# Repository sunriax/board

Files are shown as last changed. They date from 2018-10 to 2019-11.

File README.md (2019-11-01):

# BOARD Repository!

  

## Description

The BOARD repository is a set of Schematic and PCB files which can be used to build adapters for the STK500/STK600, Basys3 and other platforms. The design was made with Eagle and can be adapted easily. The Gerber files can also be found in the repository. We recommend to let [Elecrow](https://www.elecrow.com/) produce the PCB.

## Layouts

* [LCD Display Adapter](./display/display.md)
* [LCD Display Controller](./controller/controller.md)

## Important Notice

This files are valid for all repositories at the SUNriaX Github!
* [Readme](https://github.com/sunriax/manual/blob/master/README.md)
* [License](https://github.com/sunriax/manual/blob/master/LICENSE.md)
* [Warranty](https://github.com/sunriax/manual/blob/master/WARRANTY.md)

## Additional Information

You can find more additional information in the [manual](https://github.com/sunriax/manual/tree/master/docs) repository and/or visit the [WIKI](https://wiki.sunriax.at/) for further information (currently under construction).

If there are any further questions feel free to start an issue or contact us, we try to react as quick as possible.

---
**R. GÄCHTER, Rankweil Oct/2019**

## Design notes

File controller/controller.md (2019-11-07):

# BOARD Repository!

## Introduction

The controller layout is designed to adapt an LCD Display (e.g. Displaytech 162A/B) and control Text and other stuff through USB (UART). It can be powered through the mini USB jack. If the controller is used the first time, it it necessary to throw the [Bootloader](./Firmware/firmware.md) on the chip.

## Firmware

In [Firmware](./Firmware/firmware.md) repository the additional software to control the display is stored.

## Connection

### DISPLAY

| PIN | Function | Description |
|:---:|:---|:---|
| 1 | A | Backlight anode |
| 2 | K | Backlight cathode |
| 3 | VSS | Ground (0V) |
| 4 | VDD | Supply voltage (5V) |
| 5 | VO | Contrast Voltage |
| 6 | RS | HIGH=Data Signal/LOW=Instruction Signal  | 
| 7 | R/W | Connected to ground (0V) |
| 8 | E | Chip enable signal |
| 9 | DB0 | Data bit 0 (not connected) |
| 10  | DB1 | Data bit 1 (not connected) |
| 11  | DB2 | Data bit 2 (not connected) |
| 12  | DB3 | Data bit 3 (not connected) |
| 13  | DB4 | Data bit 4 |
| 14  | DB5 | Data bit 5 |
| 15  | DB6 | Data bit 6 |
| 16  | DB7 | Data bit 7 |

### ISP

| PIN | Function | Description |
|:---:|:---|:---|
| 1 | MISO | Master In/Slave Out |
| 2 | VCC | Power supply for ISP programming |
| 3 | SCK | Clock input |
| 4 | MOSI | Master Out/Slave In |
| 5 | RESET | System reset |
| 6 | GND | Ground connection |

## Schematic

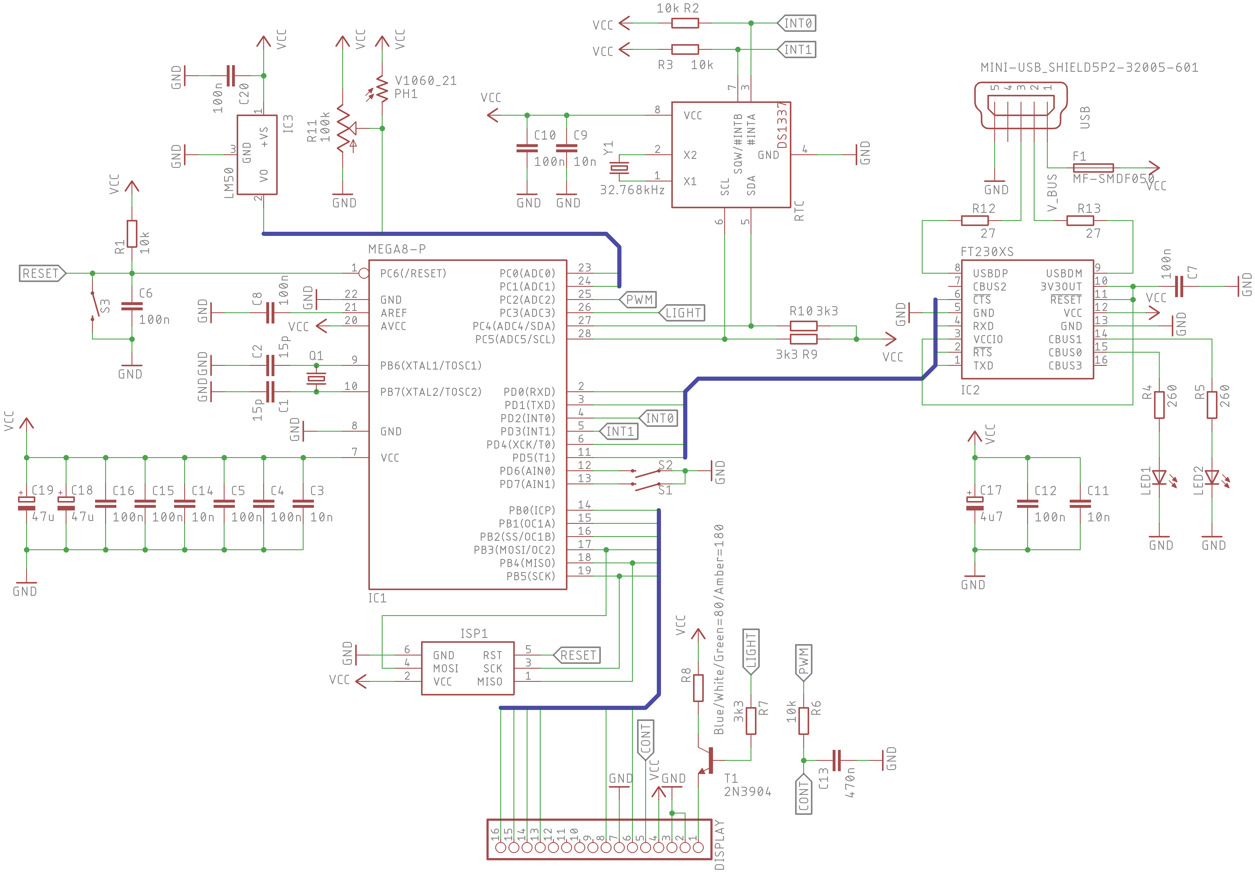
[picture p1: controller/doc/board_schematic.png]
Schematic Description


[Schematic PDF](https://raw.githubusercontent.com/sunriax/board/master/controller/doc/board_schematic.pdf)

## Board

### Bill of material

Necessary parts to build the board are documented in the THT and SMD bill of material list. We recommend to buy the parts at [RS-Components](https://at.rs-online.com/). The related numbers are deposited at the bill of material lists.

* [Bill of material THT](./partlist.csv)
* [Bill of material SMD](./partlist_SMD.csv)

### All Layers

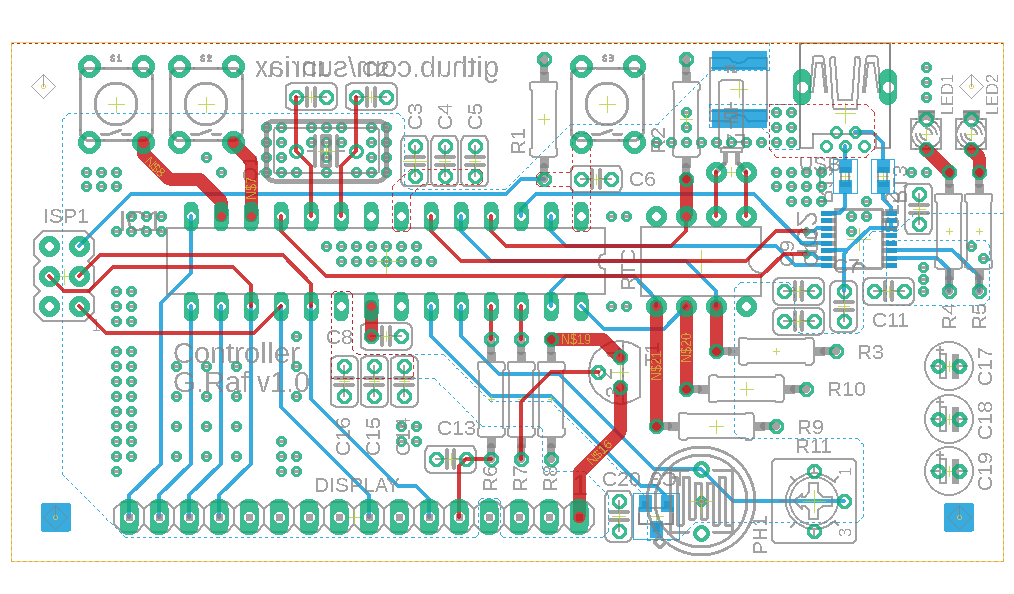
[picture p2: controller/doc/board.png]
BOARD Layer Description


[BOARD PDF](https://raw.githubusercontent.com/sunriax/board/master/controller/doc/board.pdf)

### TOP Layer

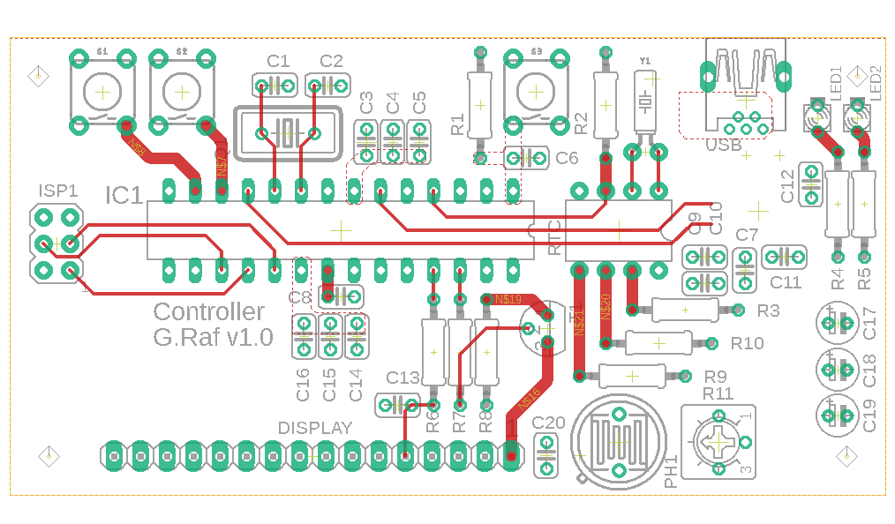
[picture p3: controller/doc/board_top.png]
TOP Layer Description


[TOP Layer PDF](https://raw.githubusercontent.com/sunriax/board/master/controller/doc/board_top.pdf)

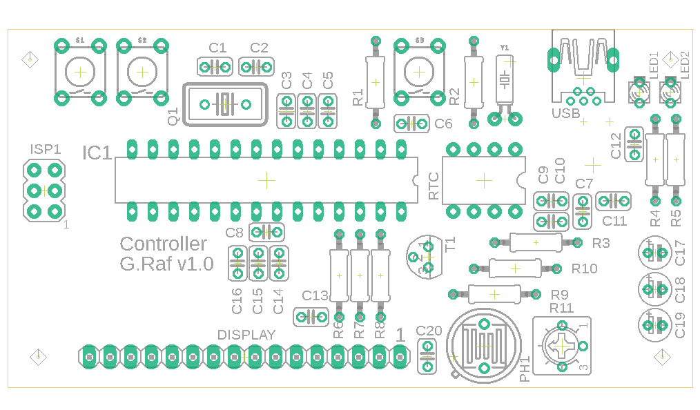
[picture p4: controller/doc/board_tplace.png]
TOP Layer Place


[TOP Layer PDF](https://raw.githubusercontent.com/sunriax/board/master/controller/doc/board_tplace.pdf)

### BOTTOM Layer

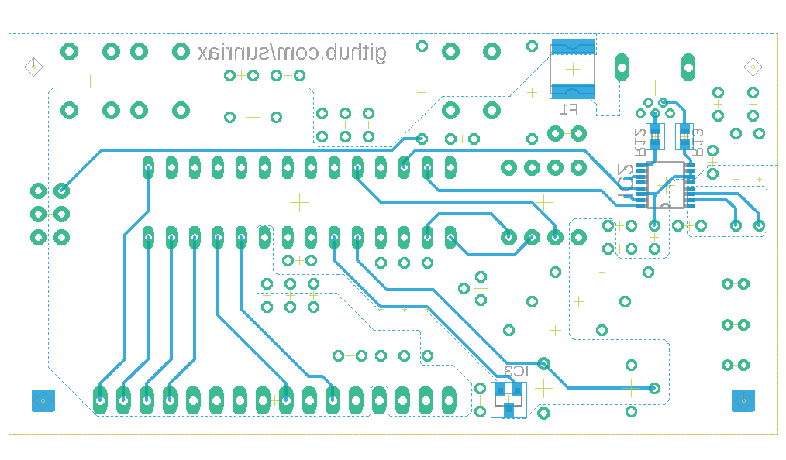
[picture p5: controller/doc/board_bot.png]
BOTTOM Layer Description


[BOTTOM Layer PDF](https://raw.githubusercontent.com/sunriax/board/master/controller/doc/board_bot.pdf)

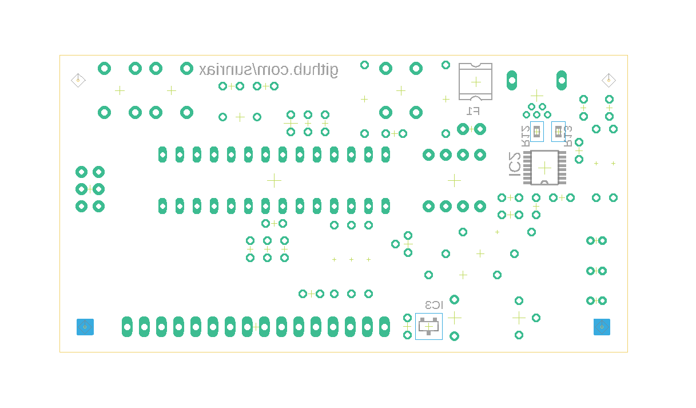
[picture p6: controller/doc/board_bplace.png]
BOTTOM Layer Place


[BOTTOM Layer PDF](https://raw.githubusercontent.com/sunriax/board/master/controller/doc/board_bplace.pdf)

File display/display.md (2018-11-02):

# BOARD Repository!

## Introduction

The display layout is designed to adapt an LCD Display (e.g. Displaytech 162A/B) to an STK500/STK600 or Basys3 development board. It also support different input voltages. If the STK500/STK600 connector is used, it is necessary that the board gets 4.5V - 5.5V, otherwise it would not work. If the Basys3 connector is used the input voltage can be 1.5V to 3.3V, the board needs an external power supply (5V) through the DC Jack!

## Connection

### JPW

| PIN | Function | Description |
|:---:|:---|:---|
| 1-2 | R/W | Read/Write mode setup through PIN5 |
| 2-3 | W (always) | Write mode only (PIN5 has no function) |

### J5V

| PIN | Function | Description |
|:---:|:---|:---|
| 1 | DB4 | Databit 4 |
| 2 | DB5 | Databit 5 |
| 3 | DB6 | Databit 6 |
| 4 | DB7 | Databit 7 |
| 5 | RW | Read/Write mode (R=HIGH/W=LOW) (JPW=1/2) |
| 6 | E | Enable data transfer |
| 7 | RS | Instruction/Data mode |
| 8 | - | Not Used |
| 9 | VCC | 4.5V - 5.5V, DC Jack not connected |
| 10  | GND | Ground connection |

### J3V3

| PIN | Function | Description |
|:---:|:---|:---|
| 1 | DB4 | Databit 4 |
| 2 | DB5 | Databit 5 |
| 3 | DB6 | Databit 6 |
| 4 | DB7 | Databit 7 |
| 5 | RW | Read/Write mode (R=HIGH/W=LOW) (JPW=1/2) |
| 6 | RS | Instruction/Data mode |
| 7 | E | Enable data transfer |
| 8 | OE | Level Shifter output enable |
| 9 | GND | Ground connection |
| 10  | GND | Ground connection |
| 11  | VCC | 1.5V - 3.3V, DC Jack connected (5V) |
| 12  | VCC | 1.5V - 3.3V, DC Jack connected (5V) |

### DISPLAY

| PIN | Function | Description |
|:---:|:---|:---|
| 1 | A | Backlight anode |
| 2 | K | Backlight cathode |
| 3 | VSS | Ground (0V) |
| 4 | VDD | Supply voltage (5V) |
| 5 | VO | Contrast Voltage |
| 6 | RS | HIGH=Data Signal/LOW=Instruction Signal  | 
| 7 | R/W | Connected to ground (0V) |
| 8 | E | Chip enable signal |
| 9 | DB0 | Data bit 0 (not connected) |
| 10  | DB1 | Data bit 1 (not connected) |
| 11  | DB2 | Data bit 2 (not connected) |
| 12  | DB3 | Data bit 3 (not connected) |
| 13  | DB4 | Data bit 4 |
| 14  | DB5 | Data bit 5 |
| 15  | DB6 | Data bit 6 |
| 16  | DB7 | Data bit 7 |

## Schematic

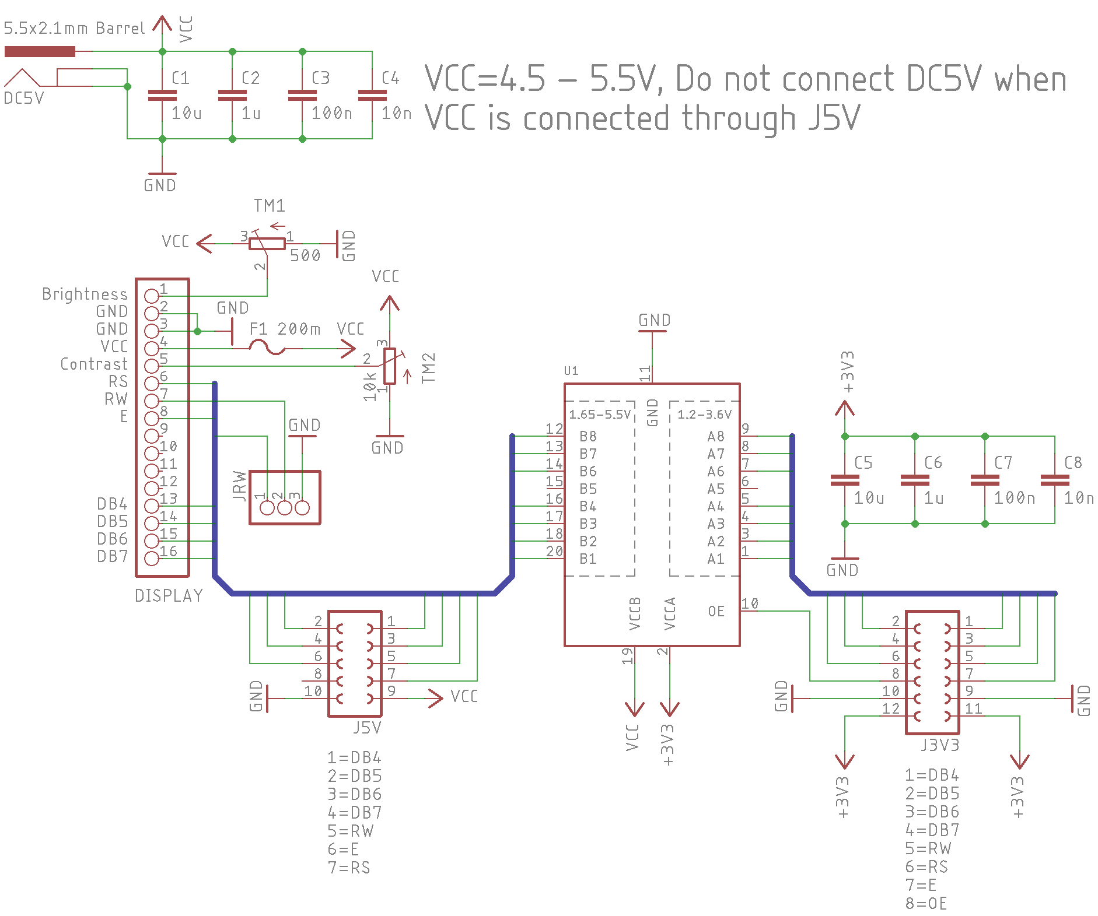
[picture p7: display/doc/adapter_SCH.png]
Schematic Description


[Schematic PDF](https://raw.githubusercontent.com/sunriax/board/master/display/doc/adapter_SCH.pdf)

## Board

### TOP Layer

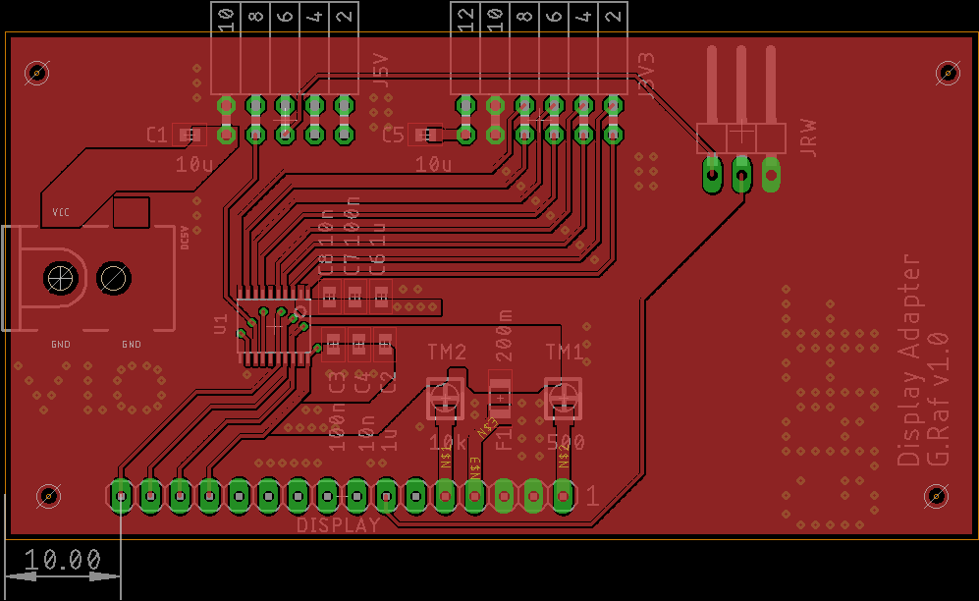
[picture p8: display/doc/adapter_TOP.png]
TOP Layer Description


[TOP Layer PDF](https://raw.githubusercontent.com/sunriax/board/master/display/doc/adapter_TOP.pdf)

### BOTTOM Layer

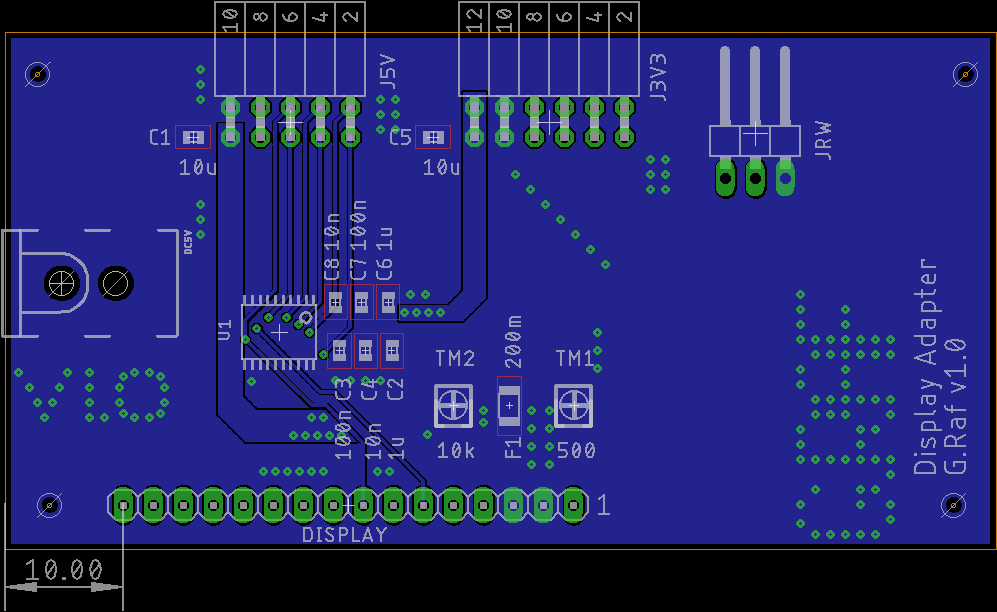
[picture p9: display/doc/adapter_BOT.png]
BOTTOM Layer Description


[BOTTOM Layer PDF](https://raw.githubusercontent.com/sunriax/board/master/display/doc/adapter_BOT.pdf)

### COMPONENT Layer

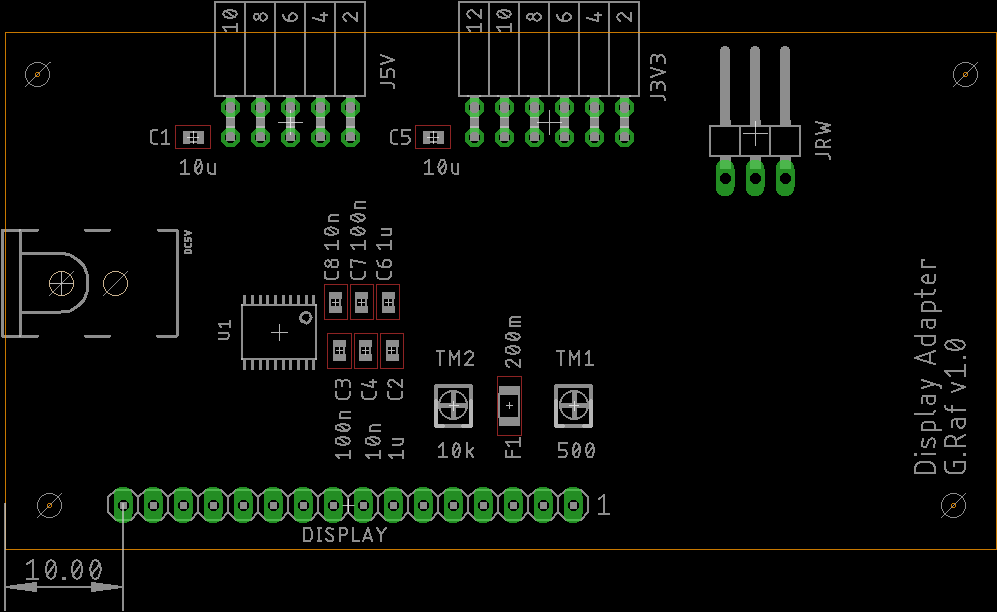
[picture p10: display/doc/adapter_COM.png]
COMPONENT Layer Description


[COMPONENT PDF](https://raw.githubusercontent.com/sunriax/board/master/display/doc/adapter_COM.pdf)

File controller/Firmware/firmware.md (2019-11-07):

# Display Controller Firmware!

   

## Description

The Firmware repository includes the Bootloader to serve the desired software to the controller over the integrated usb/uart converter (FT232). If the bootloader is burnt to the ATmega8 out of the board, it is not necessary to mount the ISP header. The FLASH and the EEPROM section can be loaded through the bootloader. To start the Bootloader it is necessary to hold the push-button S1 and S2 during reset. To quit the bootloader without writing data to the flash or the eeprom section press q.

1. Supported Controller
   * Atmel ATmega8
1. Development Hardware
   * STK500 ([Atmel](http://www.microchip.com/webdoc/stk500/index.html))
   * Display Controller
1. Additional Hardware
   * LCD Module ([Displaytech 162B](https://cdn.displaytech-us.com/sites/default/files/display-data-sheet/162B%20series-v21.pdf))
1. Development Software
   * Atmel Studio (uC C/C++)

## Getting Started

To load the demo application (controller) the bootloader has to be on the target (for direct access use an ISP programmer). Run the Bootloader over a console software (e.g. TeraTerm) and setup serial settings to 8 bits, no parity, 1 stopbit and flow control xon/xoff. After that hold the push buttons S1 and S2 and reset the controller. Now the content of controller.hex and the controller.eep can directly be pasted into the console. After loading the demo application should start.

## Important Notice

This files are valid for all repositories at the SUNriaX Github!
* [Readme](https://github.com/sunriax/manual/blob/master/README.md)
* [License](https://github.com/sunriax/manual/blob/master/LICENSE.md)
* [Warranty](https://github.com/sunriax/manual/blob/master/WARRANTY.md)

## Additional Information

You can find more additional information in the [manual](https://github.com/sunriax/manual/tree/master/docs) repository and/or visit the [WIKI](https://wiki.sunriax.at/) for further information (currently under construction).

If there are any further questions feel free to start an issue or contact us, we try to react as quick as possible.

---
**R. GÄCHTER, Rankweil Dec/2019**

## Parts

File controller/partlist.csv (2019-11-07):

Qty | Value | Parts | Description | RS Online | RS Online
1 | 16 MHz | Q1 | CRYSTAL | 814-9440
1 | Rot | LED1 (Rot) | LED | 228-5922
1 | Gruen | LED2 (Gruen) | LED | 228-5944
1 |  | DISPLAY | PIN HEADER | 674-1546
1 | 100k | R11 | POTENTIOMETER | 522-0906
10 | 100n | C4 / C5 / C6 / C7 / C8 / C10 / C12 / C15 / C16 / C20 | CAPACITOR / European symbol | 538-1310
4 | 10k | R1 / R2 / R3 / R6 / R7 | RESISTOR / European symbol | 707-8906
4 | 10n | C3 / C9 / C11 / C14 | CAPACITOR / European symbol | 538-1180
2 | 15p | C1 / C2 | CAPACITOR / European symbol | 133-5669
1 | 56R | R4 | RESISTOR / European symbol | 707-8845
1 | 36R | R5 | RESISTOR / European symbol | 707-8845
2 | 27R | R12 / R13 | RESISTOR / European symbol | 866-7121
1 | 2N3904 | T1 | NPN TRANSISTOR | 739-0442
1 | 32.768kHz | Y1 | 32.768kHz Crystal | 171-0553
2 | 3k3 | R9 / R10 | RESISTOR / European symbol | 707-8883
1 | 470n | C13 | CAPACITOR / European symbol | 801-5394
3 | 10u | C18 / C19 | POLARIZED CAPACITOR / European symbol | 116-868
1 | AVRISP-6 | ISP1 | AVR ISP HEADER | 832-3705 | 832-3496
1 | Blue/White/Green=68/Amber=180 | R8 | RESISTOR / European symbol | 806-6512 | 135-803
1 | DS1337 | RTC | DS1337 - Maxim RTC without battery backup | 786-0749
1 | FT230XS | IC2 | USB to BASIC UART IC | 757-0010
1 | LM50 | IC3 | SOT-23 Single-Supply Centigrade Temperature Sensor | 535-9846
1 | MEGA8-P | IC1 | MICROCONTROLLER | 131-0338
1 | MF-SMDF050 | F1 | MF-SMDF Series - PRC Resettable Fuses | 647-7995
1 | MINI-USB_SHIELD5P2-32005-601 | USB | MINI USB-B R/A DIP 5pol. | 515-2005
3 | MOMENTARY-SWITCH-SPST-PTH-6.0MM | S1 / S2 / S3 | Momentary Switch (Pushbutton) - SPST | 479-1413
1 | V1060_21 | PH1 | Sensor Street Light control | 914-6710

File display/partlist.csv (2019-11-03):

Qty | Value | Device | Package | Parts | Description | MF | RS-Online
1 |  | FE05-2W | FE05-2W | J5V | FEMALE HEADER |  | 135-5026
1 |  | FE06-2W | FE06-2W | J3V3 | FEMALE HEADER |  | 832-3547
1 |  | FE16W | 1X16 | DISPLAY | PIN HEADER |  | 674-1546
1 |  | PINHD-1X3/90 | 1X03/90 | JRW | PIN HEADER |  | 828-1654
1 |  | TXB0108PWR | TSSOP20 | U1 | 8-Bit Bi-Directional Level Shifter |  | 709-9038
2 | 100n | C-EUC0603 | C0603 | C3 / C7 | CAPACITOR / European symbol |  | 801-5237
1 | 10k | TRIMPOTTC33X | TC33X | TM2 | SMT trimmer potentiometer part number TC33X |  | 486-7526
2 | 10n | C-EUC0603 | C0603 | C4 / C8 | CAPACITOR / European symbol |  | 264-4630
2 | 10u | C-EUC0603 | C0603 | C1 / C5 | CAPACITOR / European symbol |  | 815-1377
2 | 1u | C-EUC0603 | C0603 | C2 / C6 | CAPACITOR / European symbol |  | 801-5243
1 | 500 | TRIMPOTTC33X | TC33X | TM1 | SMT trimmer potentiometer part number TC33X |  | 486-7582
1 | 200m | PTCFUSE-1206 | R1206 | F1 | PTC fuses / resettable thermistors |  | 647-8279
1 | 5.5x2.1mm Barrel | POWER_JACKSMD | POWER_JACK_SMD | DC5V | Power Jack Connector |  | 122-4878

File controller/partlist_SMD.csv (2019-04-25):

Qty | Value | Device | Package | Parts | Description | MF | MPN | RS Online
2 | 27R | R-EU_R0603 | R0603 | R12 | R13 | RESISTOR | European symbol |  | 866-7121
1 | FT230XS | FT230XS | SSOP16 | IC2 | USB to BASIC UART IC |  |  | 757-0010
1 | LM50 | LM50 | SOT23 | IC3 | SOT-23 Single-Supply Centigrade Temperature Sensor |  |  | 535-9846
1 | MF-SMDF050 | MF-SMDF050 | MF-SMDF050 | F1 | MF-SMDF Series - PRC Resettable Fuses |  |  | 647-7995
1 | MINI-USB_SHIELD5P2-32005-601 | MINI-USB_SHIELD5P2-32005-601 | 32005-601 | USB | MINI USB-B R/A DIP 5pol. |  |  | 515-2005

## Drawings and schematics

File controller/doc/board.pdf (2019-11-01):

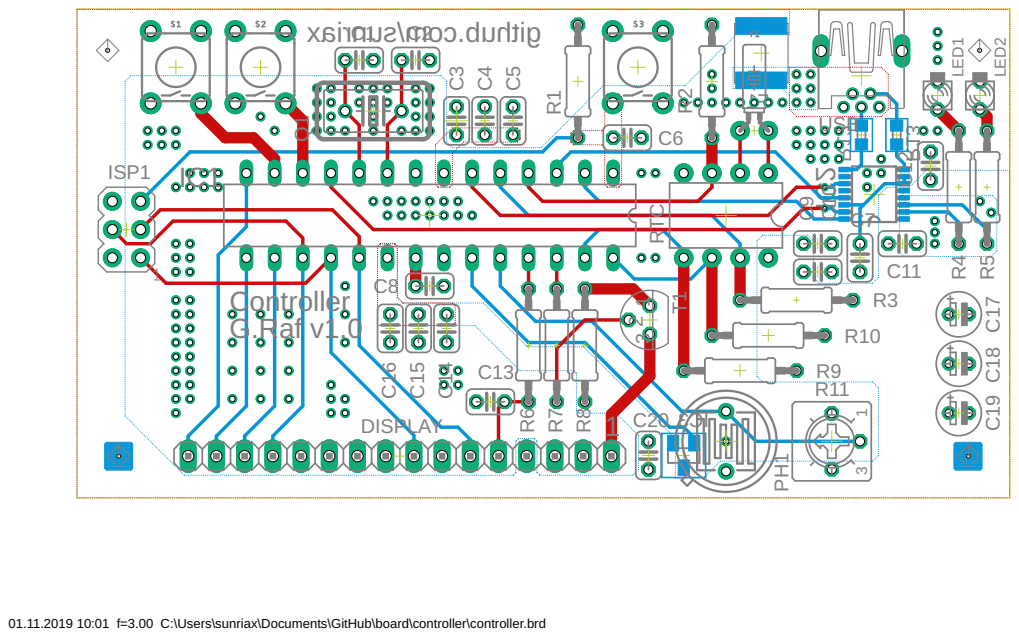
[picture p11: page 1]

01.11.2019 10:01 f=3.00 C:\Users\sunriax\Documents\GitHub\board\controller\controller.brd

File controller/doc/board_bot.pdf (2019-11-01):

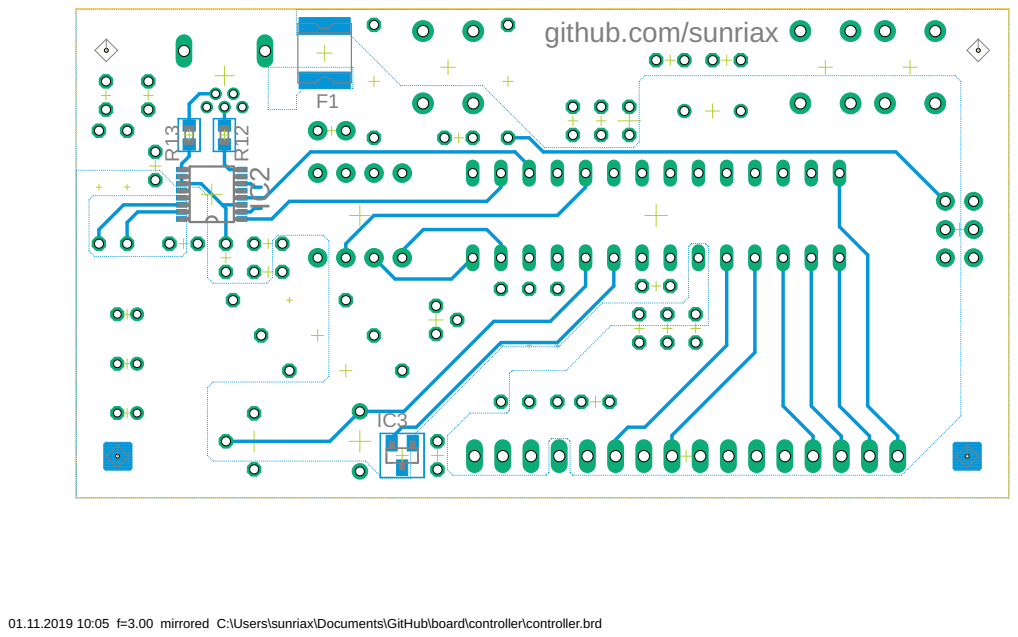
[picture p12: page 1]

01.11.2019 10:05 f=3.00 mirrored C:\Users\sunriax\Documents\GitHub\board\controller\controller.brd

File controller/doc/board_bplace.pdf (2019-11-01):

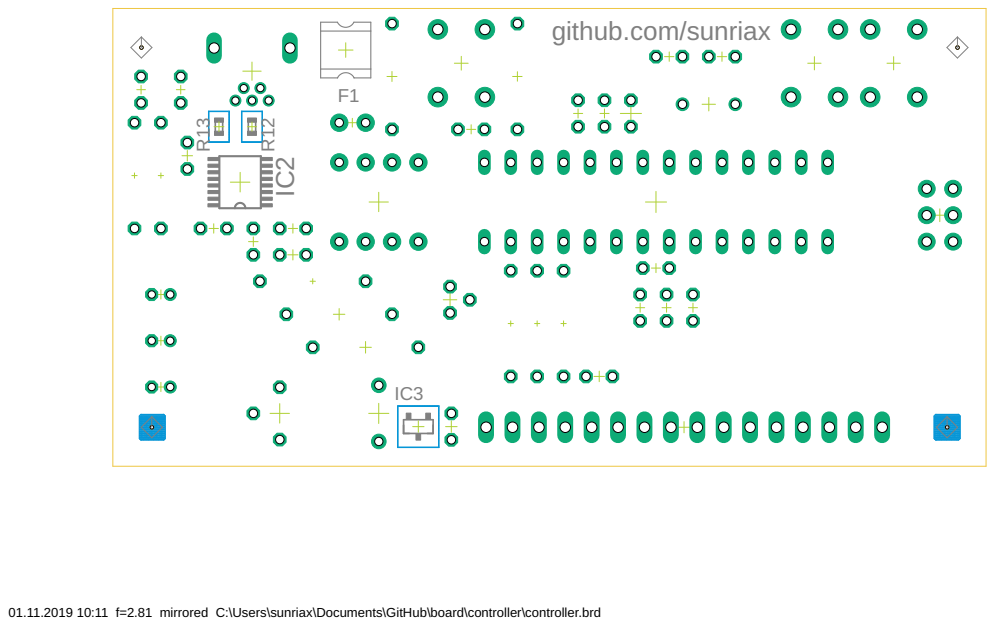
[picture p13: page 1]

01.11.2019 10:11 f=2.81 mirrored C:\Users\sunriax\Documents\GitHub\board\controller\controller.brd

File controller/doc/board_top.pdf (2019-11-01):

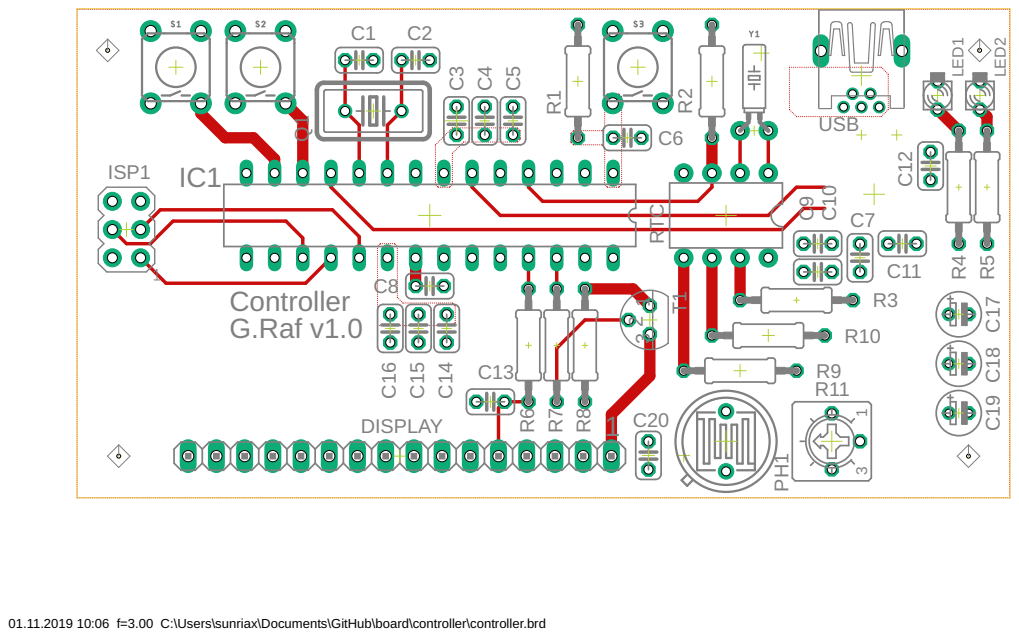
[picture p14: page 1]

01.11.2019 10:06 f=3.00 C:\Users\sunriax\Documents\GitHub\board\controller\controller.brd

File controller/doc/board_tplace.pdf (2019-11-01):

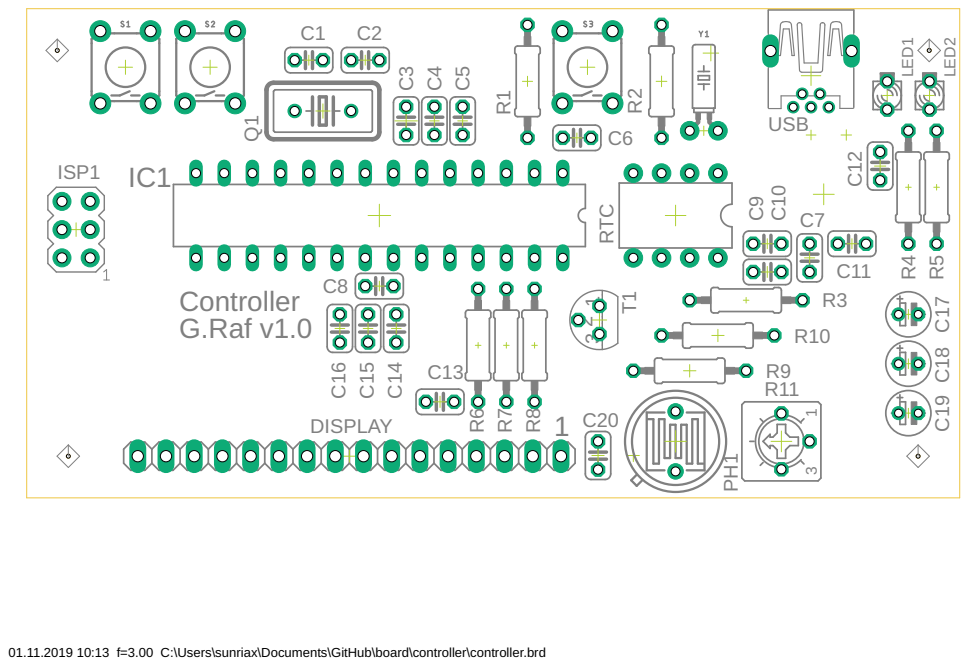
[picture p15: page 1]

01.11.2019 10:13 f=3.00 C:\Users\sunriax\Documents\GitHub\board\controller\controller.brd

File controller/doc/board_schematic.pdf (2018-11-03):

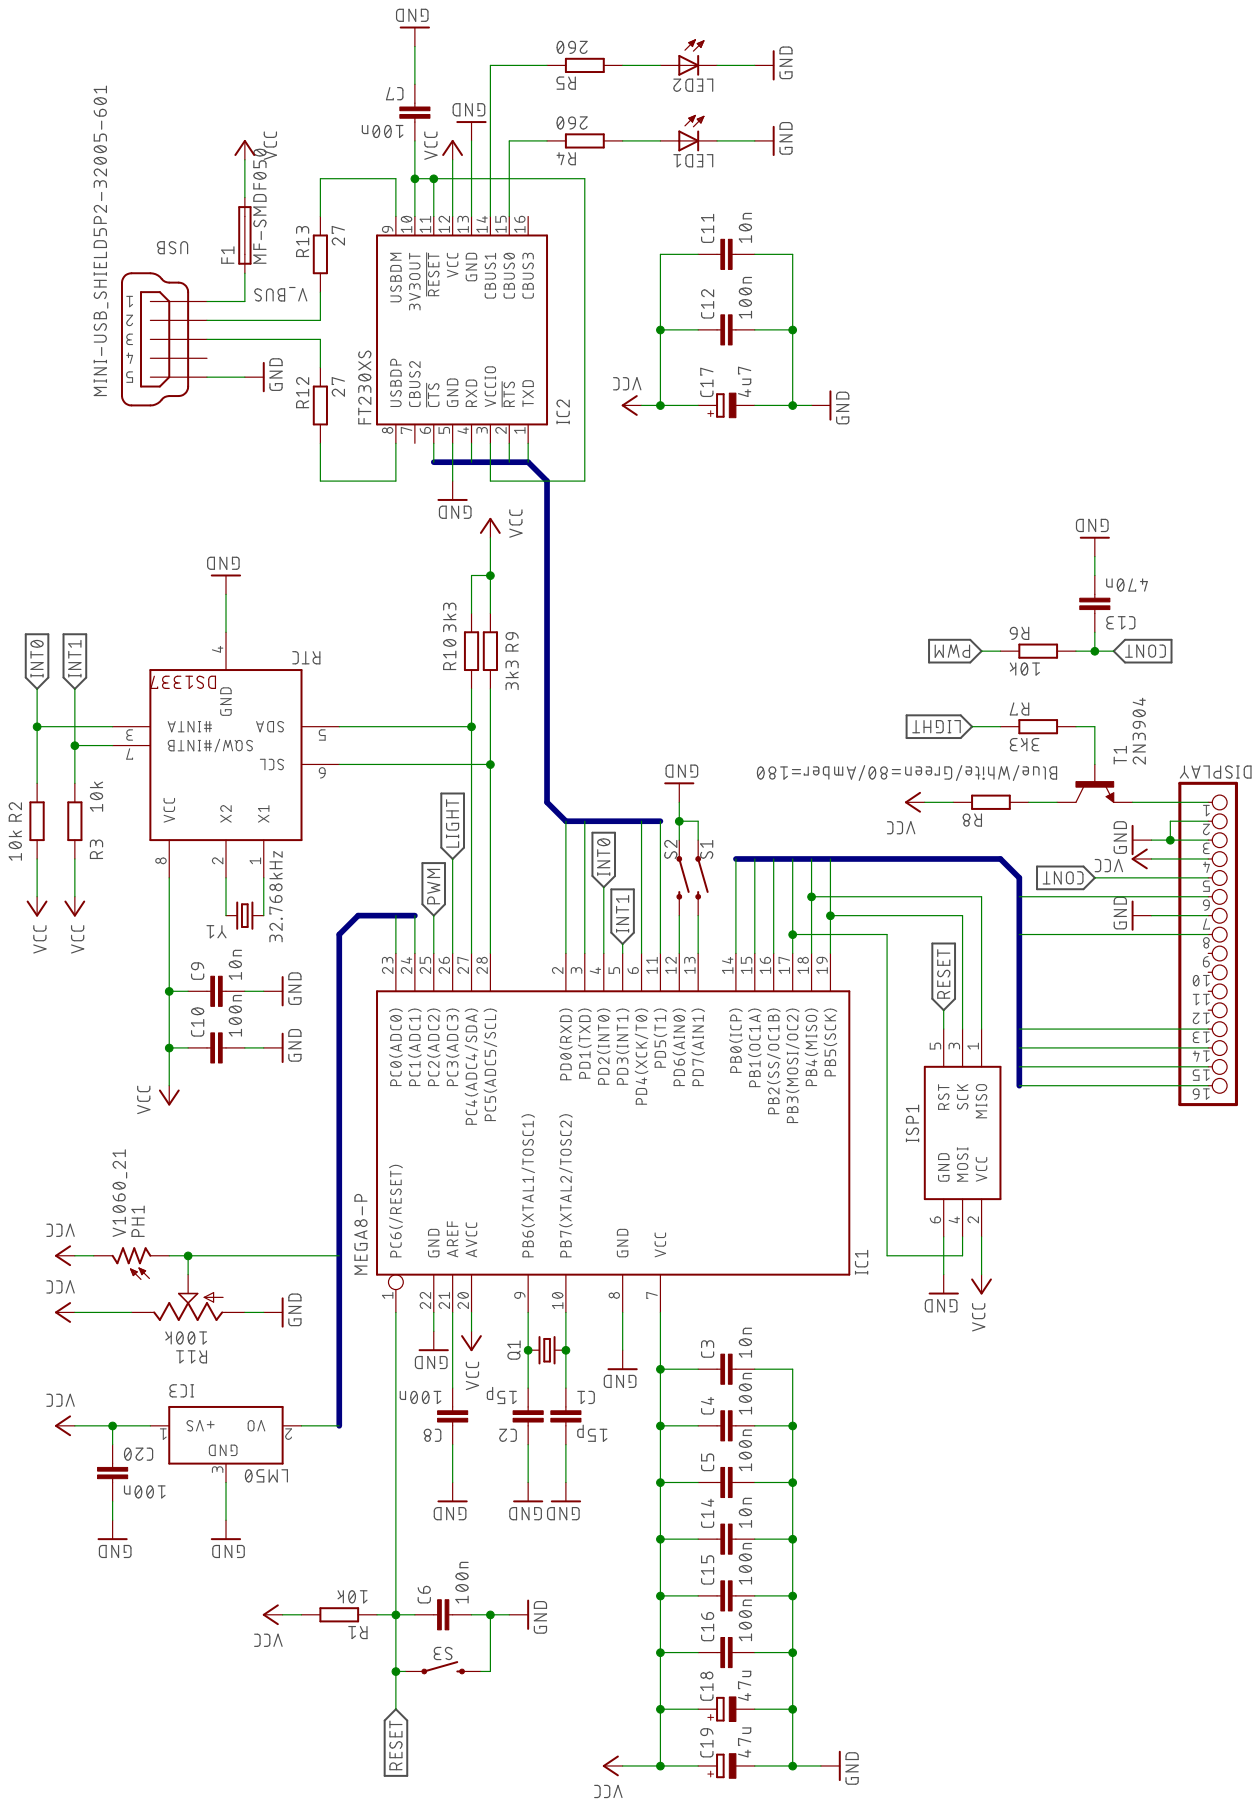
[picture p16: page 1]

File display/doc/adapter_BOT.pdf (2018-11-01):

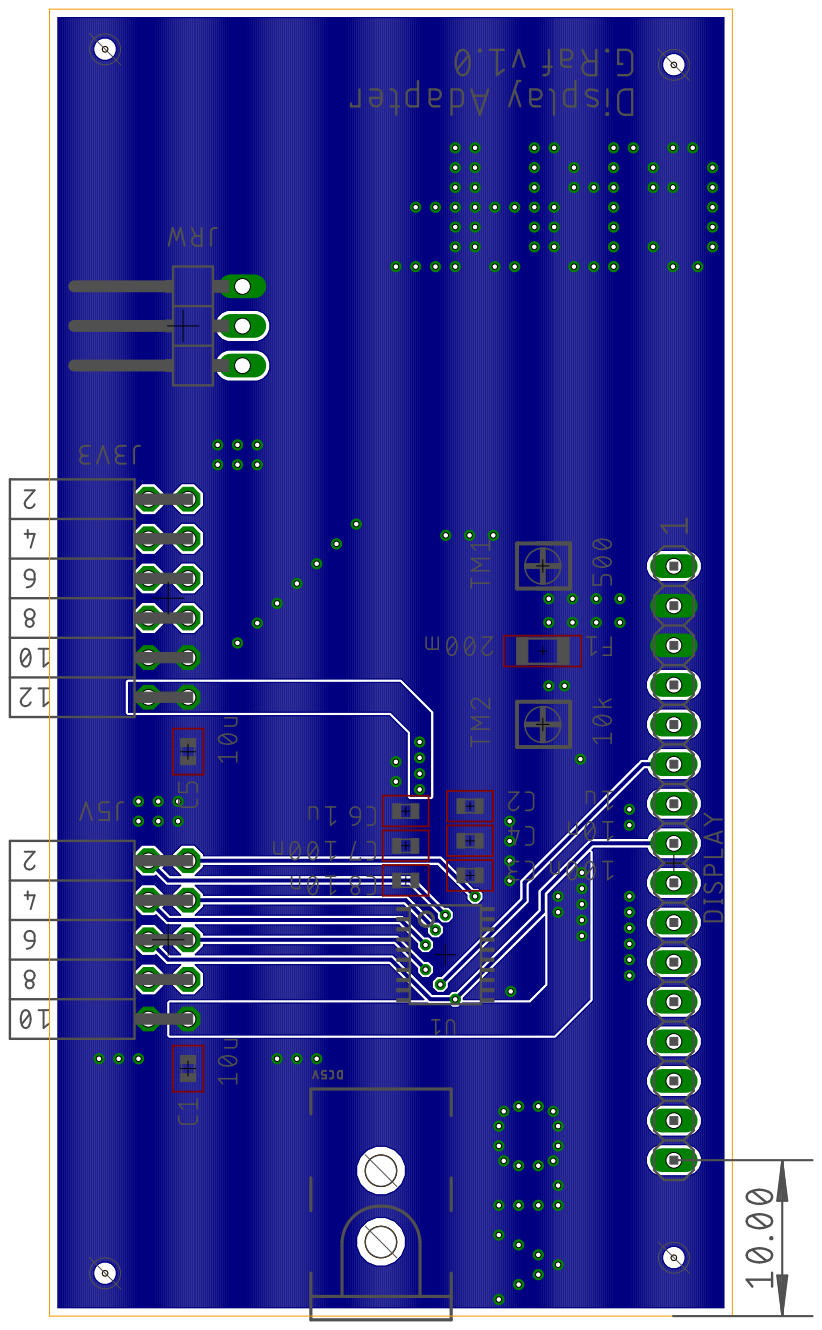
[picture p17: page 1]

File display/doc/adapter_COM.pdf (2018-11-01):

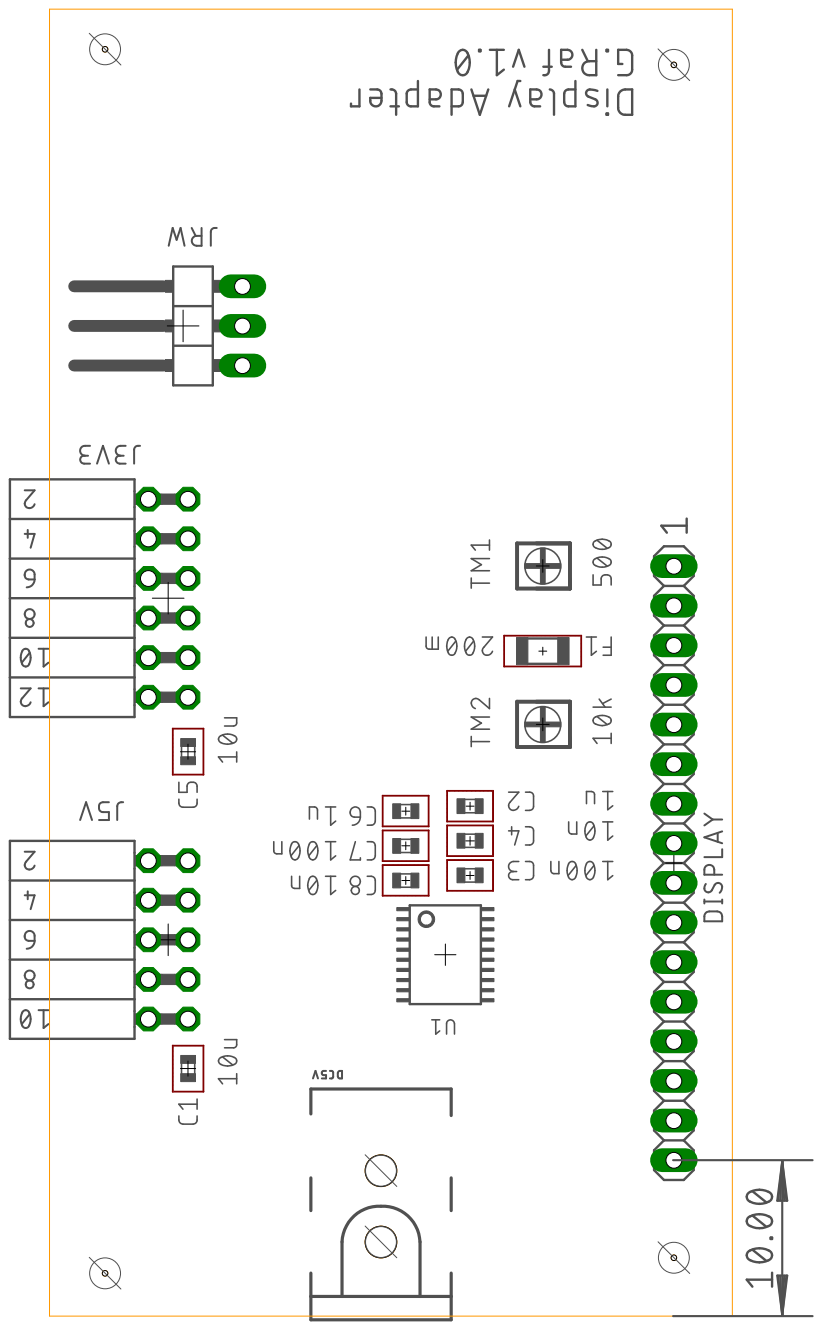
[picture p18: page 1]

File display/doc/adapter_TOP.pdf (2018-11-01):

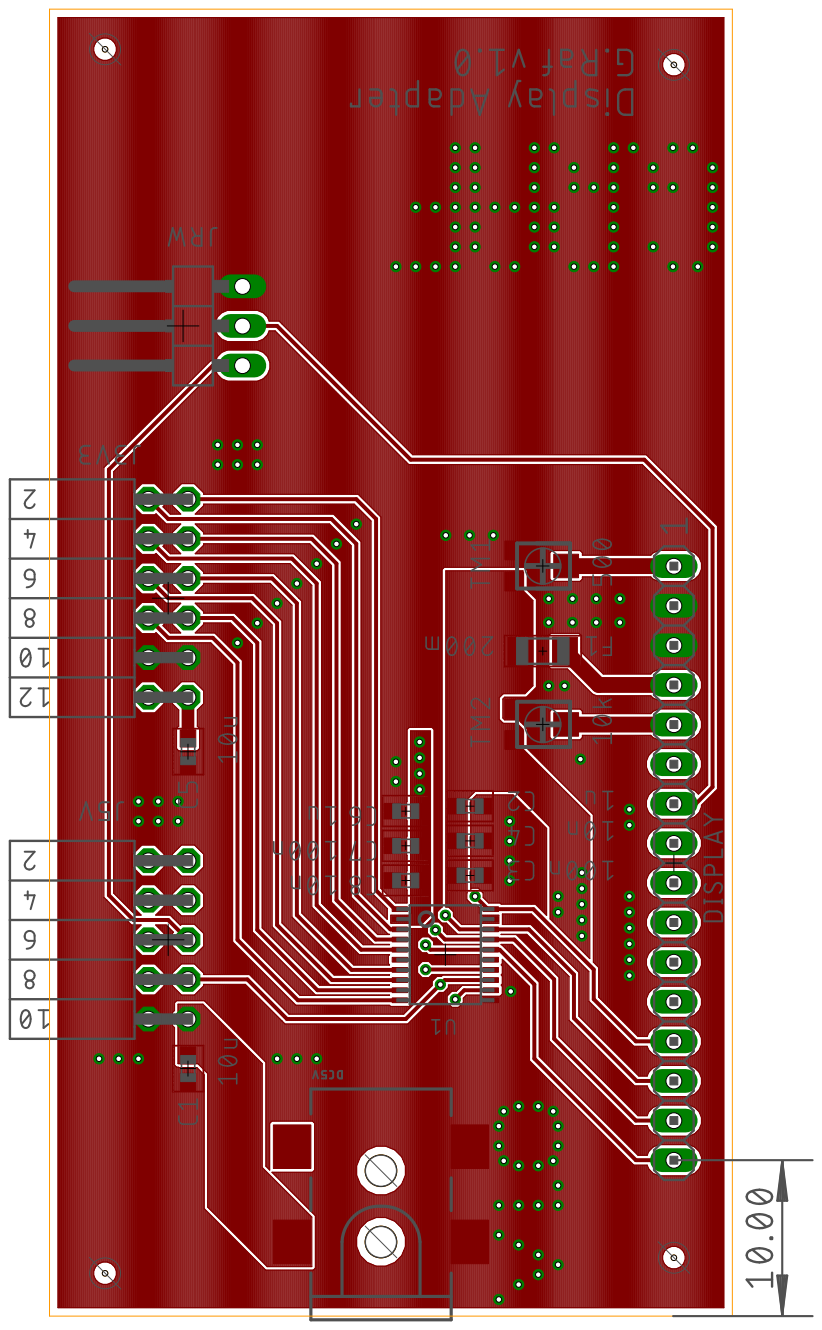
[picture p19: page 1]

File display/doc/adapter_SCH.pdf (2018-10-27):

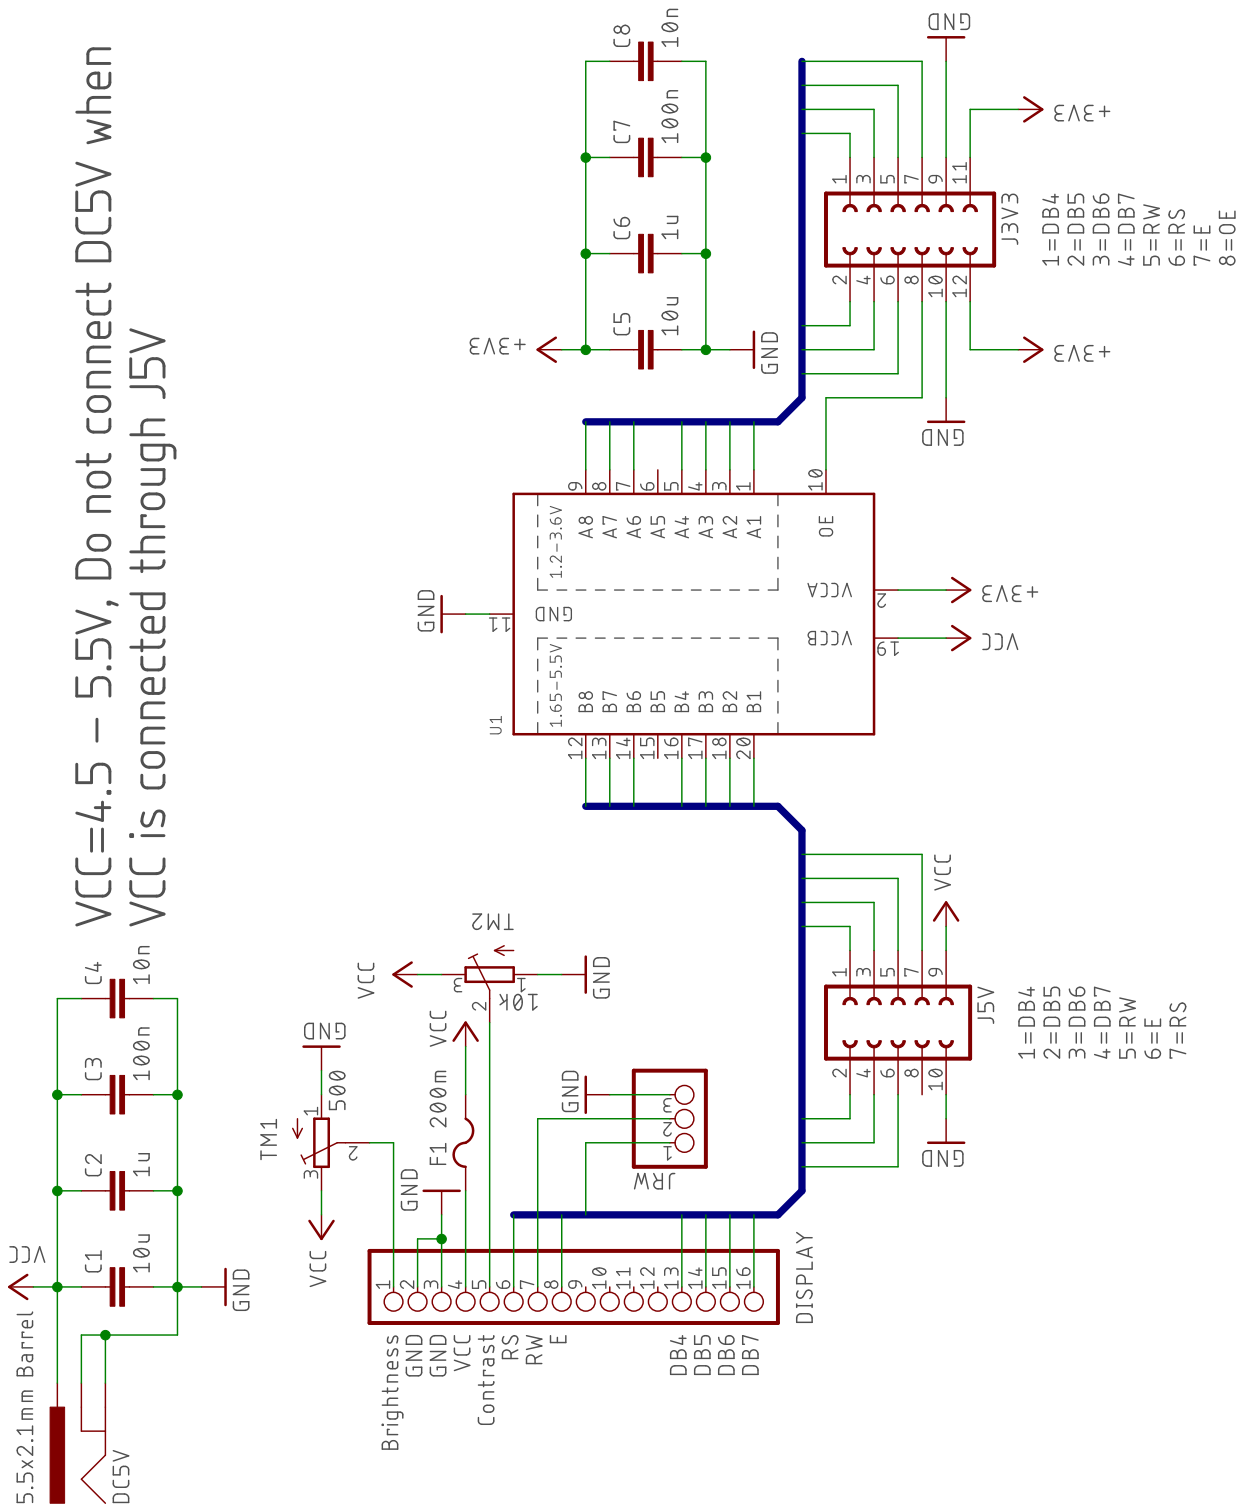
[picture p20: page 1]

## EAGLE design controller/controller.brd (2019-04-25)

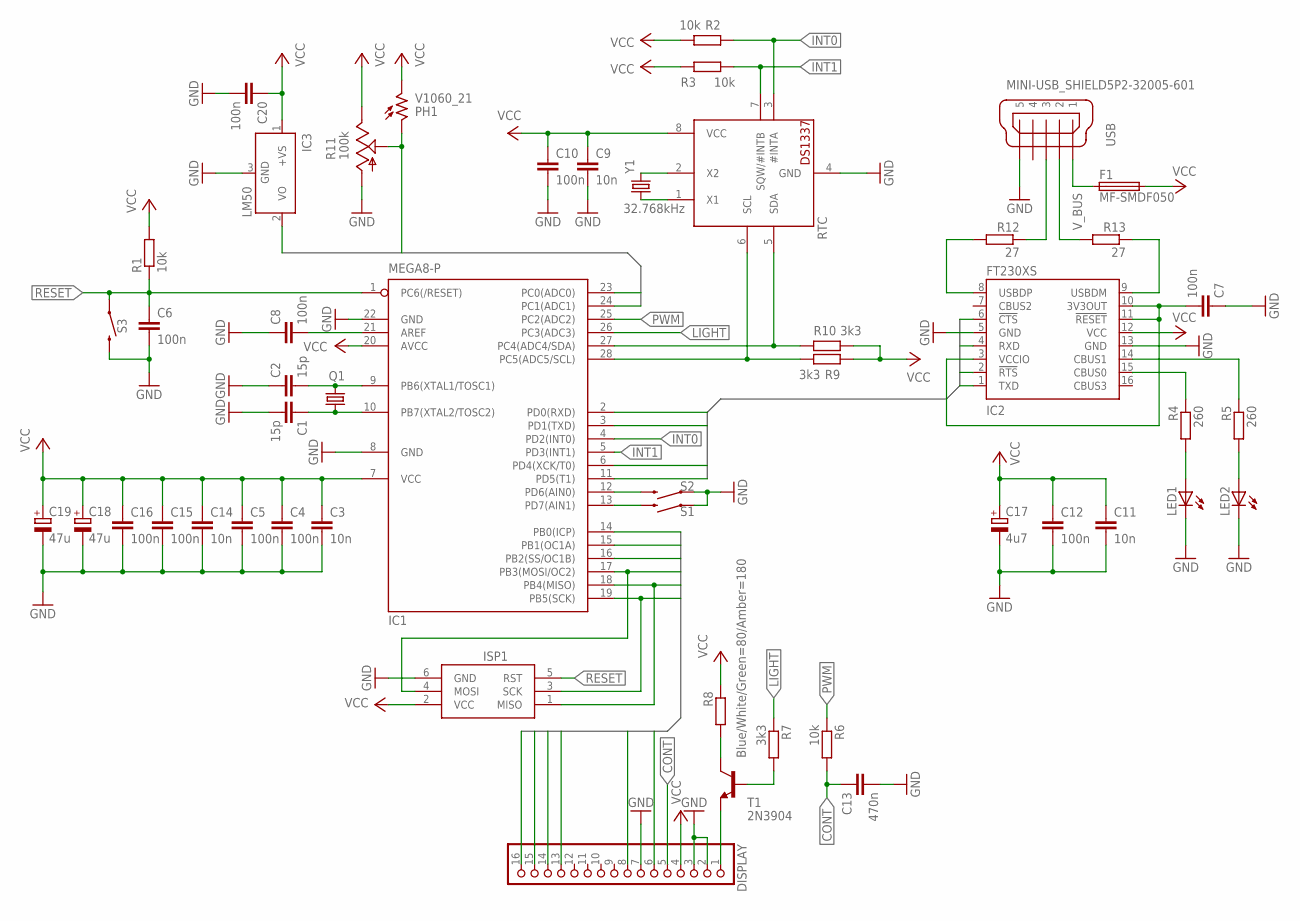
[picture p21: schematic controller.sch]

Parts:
C1, C2: 15p; C025-024X044
C3, C9, C11, C14: 10n; C025-024X044
C4, C5, C6, C7, C8, C10, C12, C15, C16, C20: 100n; C025-024X044
C13: 470n; C025-024X044
C17: 4u7; E1,8-4
C18, C19: 47u; E1,8-4
DISPLAY: PINHD-1X16; 1X16
F1: MF-SMDF050
IC1: MEGA8-P; DIL28-3
IC2: FT230XS; SSOP16
IC3: LM50; SOT23
ISP1: AVRISP-6; AVRISP
LED1, LED2: LED_ELD260; LED_LD260
PH1: V1060_21; TO-5_V10
Q1: CRYSTALHC18U-V; HC18U-V
R1, R2, R3, R6: 10k; 0207/10
R4, R5: 260; 0207/10
R7, R9, R10: 3k3; 0207/10
R8: Blue/White/Green=80/Amber=180; 0207/10
R11: 100k; CT6
R12, R13: 27; R0603
RTC: DS1337; DIL08-ROUND
S1, S2, S3: MOMENTARY-SWITCH-SPST-PTH-6.0MM; TACTILE_SWITCH_PTH_6.0MM
T1: 2N3904; TO92
USB: MINI-USB_SHIELD5P2-32005-601; 32005-601
Y1: 32.768kHz; CRYSTAL-PTH-2X6-CYL

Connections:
ADC0: IC1.23 (PC0(ADC0)), IC3.2 (VO)
ADC1: IC1.24 (PC1(ADC1)), PH1.1, R11.S
CONT: C13.1, DISPLAY.5, R6.2
CTS: IC1.6 (PD4(XCK/T0)), IC2.6 (!CTS)
DB4: DISPLAY.13, IC1.17 (PB3(MOSI/OC2)), ISP1.4 (MOSI)
DB5: DISPLAY.14, IC1.16 (PB2(SS/OC1B))
DB6: DISPLAY.15, IC1.15 (PB1(OC1A))
DB7: DISPLAY.16, IC1.14 (PB0(ICP))
E: DISPLAY.8, IC1.18 (PB4(MISO)), ISP1.1 (MISO)
GND: C1.2, C2.1, C3.2, C4.2, C5.2, C6.2, C7.1, C8.1, C9.2, C10.2, C11.2, C12.2, C13.2, C14.2, C15.2, C16.2, C17.-, C18.-, C19.-, C20.2, DISPLAY.2, DISPLAY.3, DISPLAY.7, IC1.8 (GND), IC1.22 (GND), IC2.5 (GND), IC2.13 (GND), IC3.3 (GND), ISP1.6 (GND), LED1.K (C), LED2.K (C), R11.A, RTC.4 (GND), S1.1, S2.1, S3.3 (2), USB.5
INT0: IC1.4 (PD2(INT0)), R2.1, RTC.3 (#INTA)
INT1: IC1.5 (PD3(INT1)), R3.2, RTC.7 (SQW/#INTB)
LIGHT: IC1.26 (PC3(ADC3)), R7.1
unnamed: C2.2, IC1.9 (PB6(XTAL1/TOSC1)), Q1.2
unnamed: C1.1, IC1.10 (PB7(XTAL2/TOSC2)), Q1.1
unnamed: R13.2, USB.2
unnamed: C8.2, IC1.21 (AREF)
unnamed: IC2.15 (CBUS0), R4.1
unnamed: R12.1, USB.3
unnamed: IC1.12 (PD6(AIN0)), S2.3 (2)
unnamed: IC1.13 (PD7(AIN1)), S1.3 (2)
unnamed: IC2.8 (USBDP), R12.2
unnamed: IC2.9 (USBDM), R13.1
unnamed: C7.2, IC2.3 (VCCIO), IC2.10 (3V3OUT), IC2.11 (!RESET)
unnamed: IC2.14 (CBUS1), R5.1
unnamed: LED1.A, R4.2
unnamed: LED2.A, R5.2
unnamed: DISPLAY.1, T1.3 (E)
unnamed: RTC.2 (X2), Y1.1
unnamed: R7.2, T1.2 (B)
unnamed: R8.2, T1.1 (C)
unnamed: IC1.28 (PC5(ADC5/SCL)), R9.2, RTC.6 (SCL)
unnamed: IC1.27 (PC4(ADC4/SDA)), R10.1, RTC.5 (SDA)
unnamed: RTC.1 (X1), Y1.2
PWM: IC1.25 (PC2(ADC2)), R6.1
RESET: C6.1, IC1.1 (PC6(/RESET)), ISP1.5 (RST), R1.1, S3.1
RS: DISPLAY.6, IC1.19 (PB5(SCK)), ISP1.3 (SCK)
RTS: IC1.11 (PD5(T1)), IC2.2 (!RTS)
RXD: IC1.3 (PD1(TXD)), IC2.4 (RXD)
TXD: IC1.2 (PD0(RXD)), IC2.1 (TXD)
VCC: C3.1, C4.1, C5.1, C9.1, C10.1, C11.1, C12.1, C14.1, C15.1, C16.1, C17.+, C18.+, C19.+, C20.1, DISPLAY.4, F1.2, IC1.7 (VCC), IC1.20 (AVCC), IC2.12 (VCC), IC3.1 (+VS), ISP1.2 (VCC), PH1.2, R1.2, R2.2, R3.1, R8.1, R9.1, R10.2, R11.E, RTC.8 (VCC)
V_BUS: F1.1, USB.1

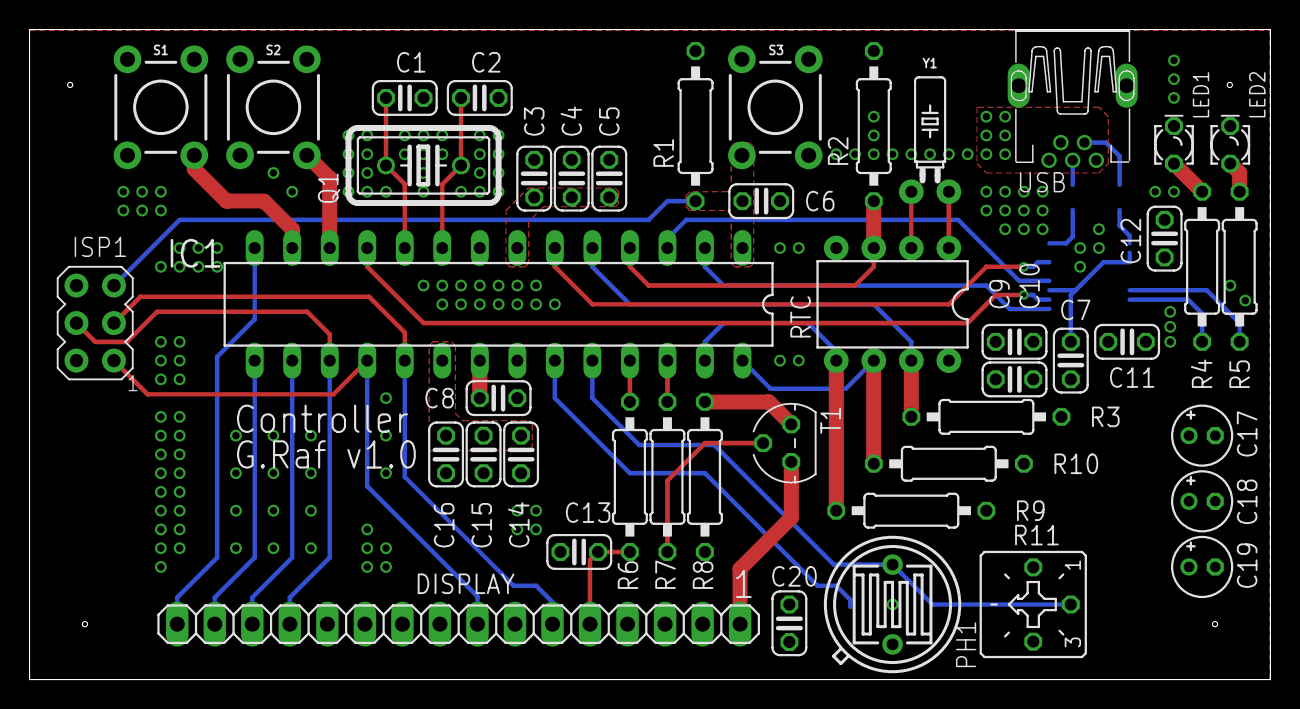
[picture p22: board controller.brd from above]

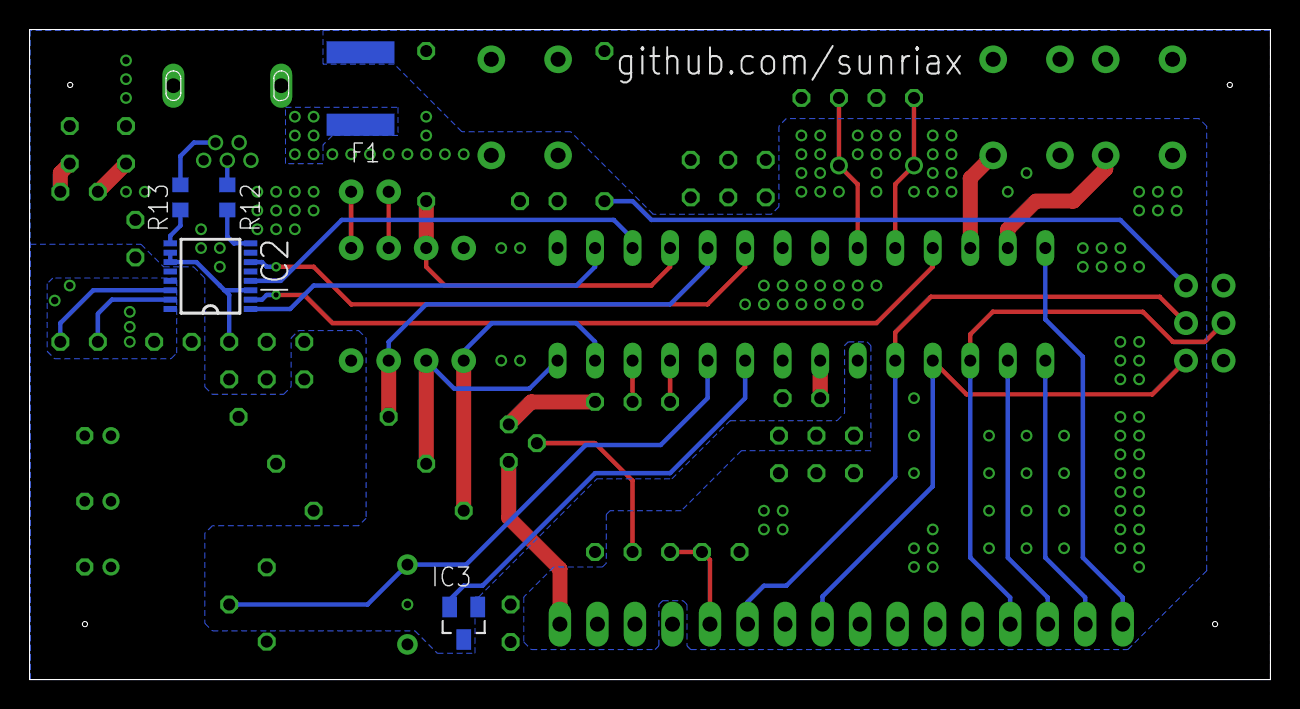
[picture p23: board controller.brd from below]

Board: 2 copper layers, 84.0 x 44.0 mm, 50 parts (5 on the bottom side), 42 nets.

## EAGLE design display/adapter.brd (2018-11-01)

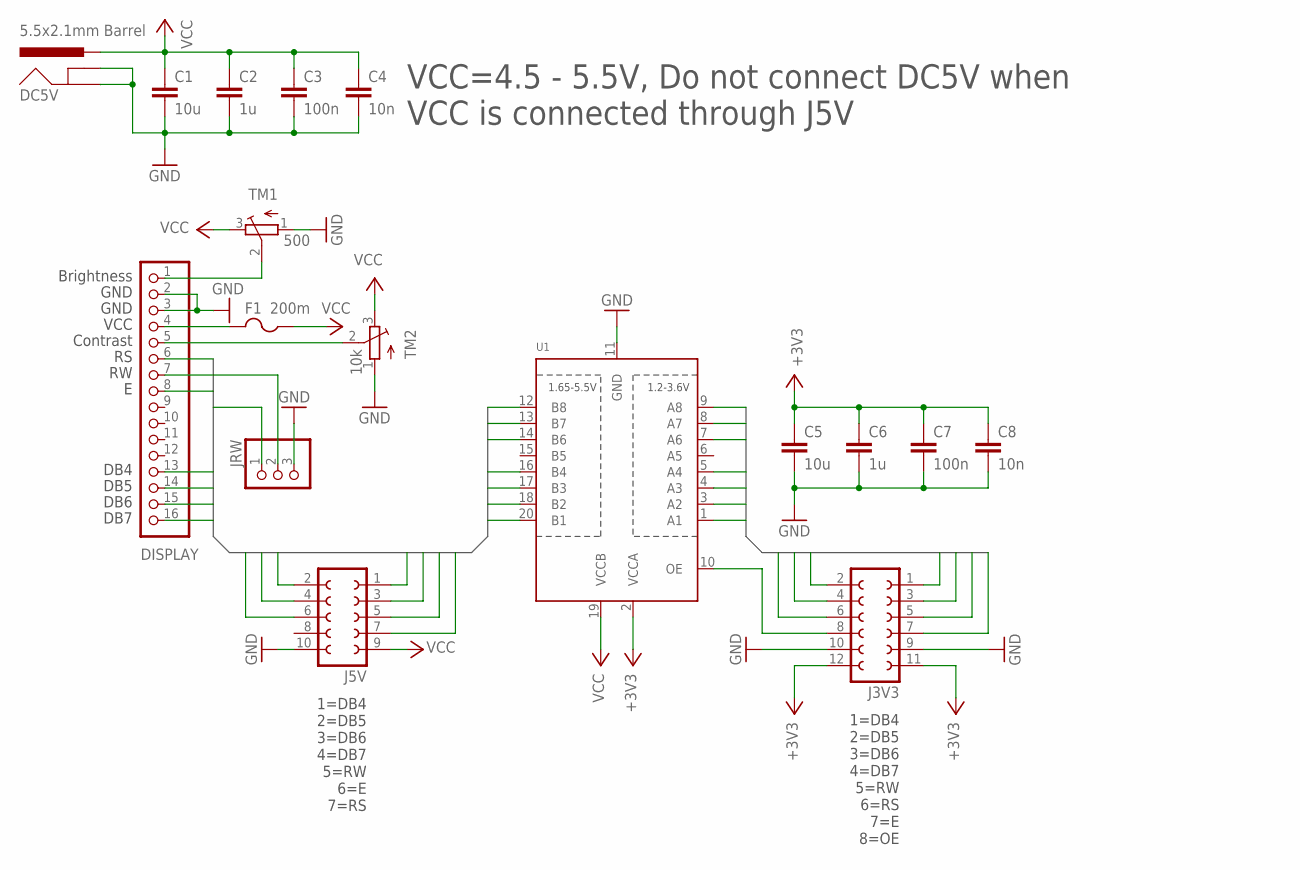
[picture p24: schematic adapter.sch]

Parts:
C1, C5: 10u; C0603
C2, C6: 1u; C0603
C3, C7: 100n; C0603
C4, C8: 10n; C0603
DC5V: 5.5x2.1mm Barrel; POWER_JACK_SMD
DISPLAY: PINHD-1X16; 1X16
F1: 200m; R1206
J3V3: FE06-2W
J5V: FE05-2W
JRW: PINHD-1X3/90; 1X03/90
TM1: 500; TC33X
TM2: 10k; TC33X
U1: TXB0108PWR; TSSOP20

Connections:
3DB4: J3V3.1, U1.1 (A1)
3DB5: J3V3.2, U1.3 (A2)
3DB6: J3V3.3, U1.4 (A3)
3DB7: J3V3.4, U1.5 (A4)
3E: J3V3.7, U1.9 (A8)
3RS: J3V3.6, U1.8 (A7)
3RW: J3V3.5, U1.7 (A6)
+3V3: C5.1, C6.1, C7.1, C8.1, J3V3.11, J3V3.12, U1.2 (VCCA)
DB4: DISPLAY.13, J5V.1, U1.20 (B1)
DB5: DISPLAY.14, J5V.2, U1.18 (B2)
DB6: DISPLAY.15, J5V.3, U1.17 (B3)
DB7: DISPLAY.16, J5V.4, U1.16 (B4)
E: DISPLAY.8, J5V.6, U1.12 (B8)
GND: C1.2, C2.2, C3.2, C4.2, C5.2, C6.2, C7.2, C8.2, DC5V.GND (GNDBREAK), DC5V.P$4 (GND), DISPLAY.2, DISPLAY.3, J3V3.9, J3V3.10, J5V.10, JRW.3, TM1.1 (A), TM2.1 (A), U1.11 (GND)
unnamed: DISPLAY.5, TM2.2 (S)
unnamed: DISPLAY.1, TM1.2 (S)
unnamed: DISPLAY.4, F1.2
unnamed: DISPLAY.7, JRW.2
unnamed: J3V3.8, U1.10 (OE)
RS: DISPLAY.6, J5V.7, U1.13 (B7)
RW: J5V.5, JRW.1, U1.14 (B6)
VCC: C1.1, C2.1, C3.1, C4.1, DC5V.VIN0 (PWR), F1.1, J5V.9, TM1.3 (E), TM2.3 (E), U1.19 (VCCB)

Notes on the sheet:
VCC=4.5 - 5.5V, Do not connect DC5V when VCC is connected through J5V
Brightness
GND
VCC
Contrast
DB4
DB5
DB6
DB7
1=DB4 2=DB5 3=DB6 4=DB7 5=RW 6=E 7=RS
1=DB4 2=DB5 3=DB6 4=DB7 5=RW 6=RS 7=E 8=OE

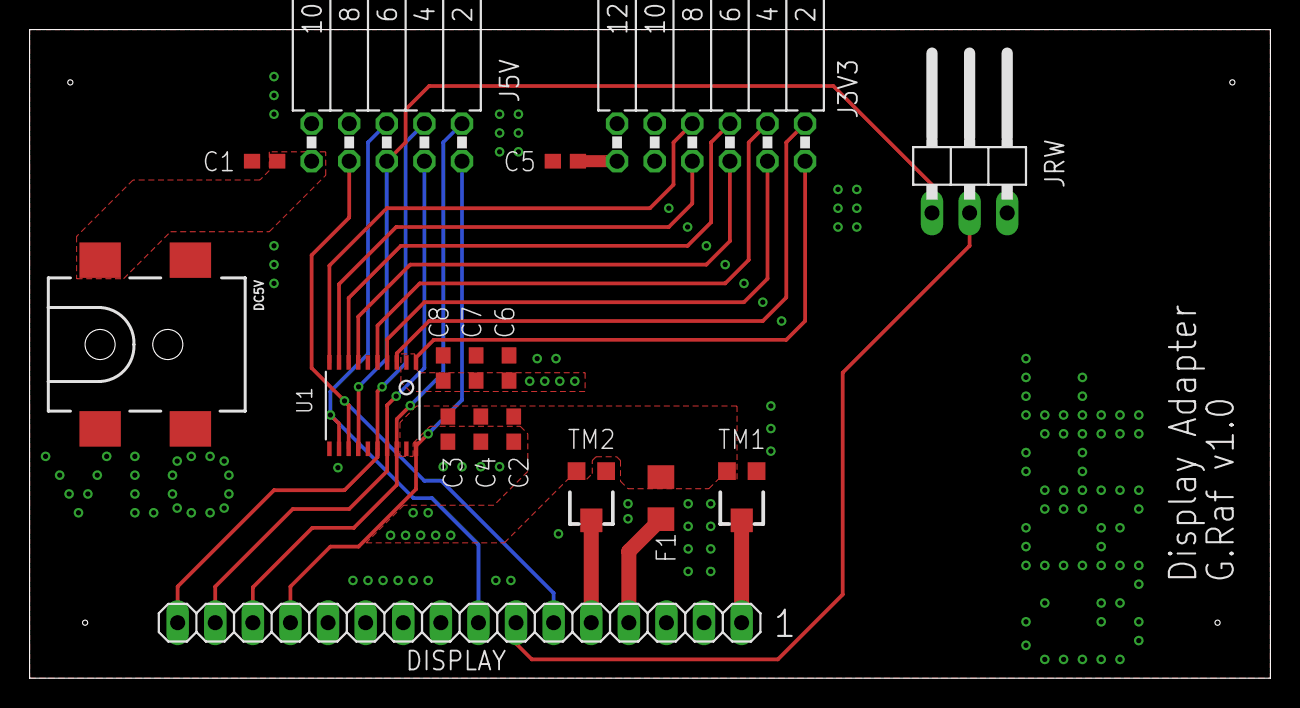
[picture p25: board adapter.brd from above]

Board: 2 copper layers, 83.8 x 43.8 mm, 17 parts (0 on the bottom side), 22 nets.

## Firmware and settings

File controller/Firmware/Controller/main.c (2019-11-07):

/* -------------------------------------
 * SUNriaX Project
 * www.sunriax.at
 * -------------------------------------
 * Hardware: Controller
 * Platform: ATmega8
 * -------------------------------------
 * Name: CONTROLLER
 * Ver.: 1.0 Release
 * Type: Executeable
 * Text: Example Software for the
 *       Controller. Display Time and
 *       Date from DS1337, temperature
 *       and light intensity. Backlight
 *       of the display is controlled
 *       by the light sensor. Data can
 *       also be catched over uart
 * -------------------------------------
 */

#include "main.h"

extern unsigned char ee_init;
extern unsigned char ee_intensity;
extern unsigned char ee_contrast;
extern unsigned char ee_offset;
extern unsigned char ee_pattern_degree[];
extern unsigned char ee_firmware[];
extern unsigned char ee_loader[];

static unsigned char init;
static unsigned char offset;
static unsigned char contrast;
static unsigned char intensity;

static unsigned char text[100];

const unsigned char pattern_degree[] =	{	0b01110, 0b01010, 0b01110, 0b00000, 0b00000, 0b00000, 0b00000, 0b00000 };
static unsigned int counter;

ISR(TIMER1_OVF_vect)
{
	DISPLAY_CTRL_PORT &= ~((1<<CONTRAST) | (1<<BACKLIGHT));
}

ISR(TIMER1_COMPA_vect)
{
	DISPLAY_CTRL_PORT |= (1<<CONTRAST);
}

ISR(TIMER1_COMPB_vect)
{
	DISPLAY_CTRL_PORT |= (1<<BACKLIGHT);
}


int main(void)
{	
	uart_init();
	uart_rts(1);
	
	// Firmware Version
	uart_set_prom(ee_firmware, 50);
	
	// Bootloader Version
	uart_set_prom(ee_loader, 50);
	
	// Application
	uart_setstring("Debug Application");
	uart_2linebreak();
	
	// Read EEPROM Data
	init = eeprom_read_byte(&ee_init);
	offset = eeprom_read_byte(&ee_offset);
	contrast = eeprom_read_byte(&ee_contrast);
	intensity = eeprom_read_byte(&ee_intensity);
	
	uart_setstring("Init:\t\t");
	uart_setvalue(init, 2);
	
	uart_setstring("Offset:\t\t");
	uart_setvalue(offset, 10);
	
	// Initialize Timer Counter1
	TCCR1A = (1<<WGM10);								// Fast PWM 8 Bit
	TCCR1B = (1<<WGM12) | (1<<CS10);					// No prescaler
	OCR1AL = contrast;
	OCR1BL = intensity;
	TIMSK  = (1<<OCIE1A) | (1<<OCIE1B) | (1<<TOIE1);	// Enable Compare Match A,B and Overflow Interrupt
	sei();												// Enable Interrupt globally
	
	uart_setstring("Contrast:\t");
	uart_setvalue(contrast, 10);

	uart_setstring("Intensity:\t");
	uart_setvalue(intensity, 10);
	
	// Initialize LCD Display
	DISPLAY_CTRL_DDR |= (1<<CONTRAST) | (1<<BACKLIGHT);
	DISPLAY_CTRL_PORT |= (1<<CONTRAST) | (1<<BACKLIGHT);
	
	uart_setstring("Initializing Input Signals");
	uart_linebreak();
	SWITCH_DDR &= ~((1<<S1) | (1<<S0));
	SWITCH_PORT |= (1<<S1) | (1<<S0);
	
	uart_setstring("Initializing Analog/Digital Converter");
	uart_linebreak();
	adc_init();
	
	uart_setstring("Initializing Two Wire Interface");
	uart_linebreak();
	twi_init(1);	// Master Mode
	
	uart_setstring("Initializing Display");
	uart_linebreak();
	lcd_init();
	
	uart_setstring("Initializing Patterns");
	uart_linebreak();
	
	for(unsigned char i=0; i < (unsigned char)(EEPROM_DISPLAY_SYMBOLS); i++)
	{
		// Write Patterns to Display
		eeprom_read_block(text, &ee_pattern_degree[(unsigned char)(i * EEPROM_DISPLAY_SYMBOL)], (unsigned char)(EEPROM_DISPLAY_SYMBOL));
		lcd_pattern((LCD_CGADDR_CHAR0 + i), text);
		
		for (unsigned char j=0; j < (unsigned char)(EEPROM_DISPLAY_SYMBOL); j++)
		{
			uart_setchar('\t');
			uart_setvalue(text[j], 2);
		}
		uart_linebreak();
	}
	uart_linebreak();
	
	//ds1337_set_time("13:15:30");
	//ds1337_set_date("06/06/19");
	
    while (1)
    {
		adc_channel(0);
		signed int temperature = adc_average(10) + offset;
		adc_channel(1);
		unsigned int intensity = adc_average(10);
		
		if(init & (1<<EEI))
		{
			int i = (218 - (float)(intensity)/(float)(2.75));
			
			if(i < 0)
			{
				i = 1;
			}
			
			OCR1BL = (unsigned char)(i);
		}
		
		temperature = (temperature * ((float)(5000)/(float)(1024)) - 500) / 10;
		
		char *ds1337_time = ds1337_get_time();
		char *ds1337_date = ds1337_get_date();
		
		// Display Time from DS1337 and Temperature
		lcd_home();
		lcd_string(ds1337_time);
		
		// Temperature
		lcd_char(' ');
		lcd_sl2ascii(temperature, 10, 3);
		lcd_char(LCD_CGADDR_CHAR0);
		
		lcd_cursor(0, 1);
		lcd_string(ds1337_date);
		
		// Intensity
		lcd_char(' ');
		lcd_ul2ascii(intensity, 10, 4);
		
		if(counter > 50)
		{
			uart_setchar('\r');
			uart_setstring("Stamp: ");
			uart_setstring(ds1337_time);
			uart_setchar('\t');
			uart_setstring(ds1337_date);
			uart_setchar('\t');
			
			static char buffer[4];
			
			itoa(temperature, buffer, 10);
			uart_setstring("Temperature: ");
			uart_setstring(buffer);
			uart_setchar('\t');
			
			itoa(intensity, buffer, 10);
			uart_setstring("Intensity: ");
			uart_setstring(buffer);
			uart_setchar(' ');
			
			counter = 0;
		}
		
		counter++;
    }
}

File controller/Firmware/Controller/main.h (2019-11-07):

/* -------------------------------------
 * SUNriaX Project
 * www.sunriax.at
 * -------------------------------------
 * Hardware: Controller
 * Platform: ATmega8
 * -------------------------------------
 * Name: CONTROLLER
 * Ver.: 1.0 Release
 * Type: Executeable
 * Text: Example Software for the
 *       Controller. Display Time and
 *       Date from DS1337, temperature
 *       and light intensity. Backlight
 *       of the display is controlled
 *       by the light sensor. Data can
 *       also be catched over uart
 * -------------------------------------
 */

#ifndef MAIN_H_
#define MAIN_H_

// System
#define F_CPU 16000000UL

// EEPROM Data
#define EEI 0

// Display
#define DISPLAY_CTRL_DDR DDRC
#define DISPLAY_CTRL_PORT PORTC
#define CONTRAST   PC2
#define BACKLIGHT  PC3

// Sensor
#define SENSOR_DDR  DDRC
#define SENSOR_PORT PORTC
#define TEMPRATURE PC0
#define INTENSITY  PC1

// DS1337 Interrupts
#define DS1337_DDR  DDRD
#define DS1337_PORT PORTD
#define INTA PD2
#define INTB PD3

// Push-Button
#define SWITCH_DDR  DDRD
#define SWITCH_PORT PORTD
#define SWITCH_PIN  PIND
#define S0 PD6
#define S1 PD7

// Libraries
#include <stdlib.h>
#include <avr/io.h>
#include <avr/interrupt.h>
#include <avr/eeprom.h>
#include <util/delay.h>

#include "../Library/adc.h"
#include "../Library/lcd.h"
#include "../Library/twi.h"
#include "../Library/uart.h"
#include "../Library/eeprom.h"
#include "../Library/ds1337.h"

#endif /* MAIN_H_ */

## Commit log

2018-10-27 Update
    Added partlist and gerber files. Updated some things on board
    [adapter.brd, adapter.sch, partlist.csv]
2018-10-31 Update
    Error correction of Display header position.
    [adapter.brd]
2018-10-31 Update
    Board should now be completed
2018-11-01 Update
    Added a new design (controller) and corrected again some things in the display project...
    [adapter.brd, controller.brd, controller.sch]
2018-11-02 Update
    Completed the controller design
    [controller.brd, controller.sch]
2018-11-02 Update
    Corrected some things and added partlist to the controller project
    [controller.brd, controller.sch, partlist.csv]
2018-11-03 Update
    Corrected wrong direction of the display header
    [controller.brd, controller.sch]
2018-11-03 Update
    Schematic update
2019-04-25 Update
    Added silkscreen PDF and seperated SMD partlist
    [controller.brd, controller.sch, partlist_SMD.csv]
2019-11-01 Corrected partlist
    [partlist.csv]
2019-11-01 Changed partlist
    Added , instead of ;
    [partlist.csv]
2019-11-01 Correction
    Changed background color of the boards and optimized pdf´s
2019-11-01 Added BOM
2019-11-07 Initial
    Initial bootloader and (demo) controller software
    [partlist.csv]
2019-11-07 CI and description adapted
    Changed some things for travis-ci and adaptet the description and changed the partlist.
    [partlist.csv]

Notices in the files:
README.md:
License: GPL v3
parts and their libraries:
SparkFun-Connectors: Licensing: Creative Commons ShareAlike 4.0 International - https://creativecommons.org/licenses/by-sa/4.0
